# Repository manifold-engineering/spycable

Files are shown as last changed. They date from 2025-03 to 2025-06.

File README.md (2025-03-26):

# Manifold Spycable  
**_Work in Progress_**

**Manifold Spycable** is a project that aims to explore the boundaries of miniaturized embedded electronics by integrating a fully functional computer within a standard XLR connector. 

---

## Overview  
The Manifold Spycable comprises several components:

### 1. **The Spycable Device**  
- A single PCB computer designed to fit inside a standard XLR connector (such as the Neutrik NC3MMX or similar) - similar form factor as [Manifold PAT-MAT](https://github.com/manifold-engineering/pat-mat)
- Powered directly from standard 48V phantom power, commonly used in professional audio equipment.  
- Equipped with:  
  - **TI PCM1820/1821/1822 ADC** for audio data conversion.  
  - **ESP8685 MCU** based on the RISC-V ESP32-C3 core with Wi-Fi capability.  
- Features a **u.FL IPEX connector** for a Wi-Fi antenna. A detailed evaluation of compatible antennas (e.g., Fractus Compact Reach Xtend with coax cable) will be added later.  
- Designed to allow space for a microphone cable to pass through, enabling the creation of standard-looking XLR cables capable of audio data transmission and recording.

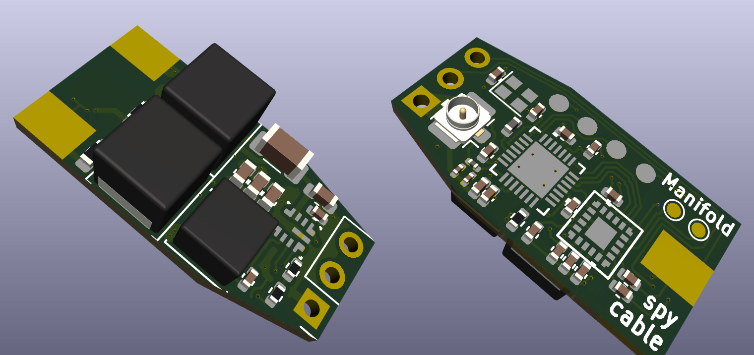
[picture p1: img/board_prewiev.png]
Board preview


### 2. **Firmware**  
Custom firmware for the ESP8685 to handle audio data acquisition from the ADC and real-time data transmission over Wi-Fi.

### 3. **Receiver Software**  
Software for standaerd computer systems to process the incoming audio data streams. Possible functions might include audio file recording and real-time playback.

---
### Development Stage  
This project is in its **early development stage**. Currently, only the hardware design for the device is ready. Firmware and receiver software development are still in progress.

**Note**: This project may have potential data security implications if used in unintended ways. However, it is intended purely for educational, experimental, and demonstration purposes.  

---

## Licensing  
This project is licensed under the **MIT License**. See the `LICENSE` file for more information.

---

## Future Development  
Stay tuned for:  
- Firmware updates for the embedded ESP8685.  
- Antenna recommendations and performance benchmarks.  
- Receiver software to enable audio recording and playback.

---

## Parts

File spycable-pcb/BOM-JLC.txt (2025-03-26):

BUCK DC DC PMIC	https://jlcpcb.com/partdetail/1973381-LMR36506MSCQRPERQ1/C1882561
C MLCC input LC	https://jlcpcb.com/partdetail/14236-CL31A106KBHNNNE/C13585
L input LC 	https://jlcpcb.com/partdetail/179374-FNR5040S502MT/C167991
C DC DC Out	https://jlcpcb.com/partdetail/71320-0603X106K160NT/C70225
L DC DC buck	https://jlcpcb.com/partdetail/179275-FNR4030S680MT/C167892 or https://jlcpcb.com/partdetail/179271-FNR4030S470MT/C167888
XTAL ESP	https://jlcpcb.com/partdetail/SeikoEpson-Q22FA12800332/C255899
ESP MCU		https://jlcpcb.com/partdetail/EspressifSystems-ESP8685H4/C4944062
Audio ADC	https://jlcpcb.com/partdetail/TexasInstruments-PCM1822IRTER/C5214995 or https://jlcpcb.com/partdetail/TexasInstruments-PCM1820IRTER/C5215004

aux: USB pogo https://www.aliexpress.com/item/1005006470782095.html

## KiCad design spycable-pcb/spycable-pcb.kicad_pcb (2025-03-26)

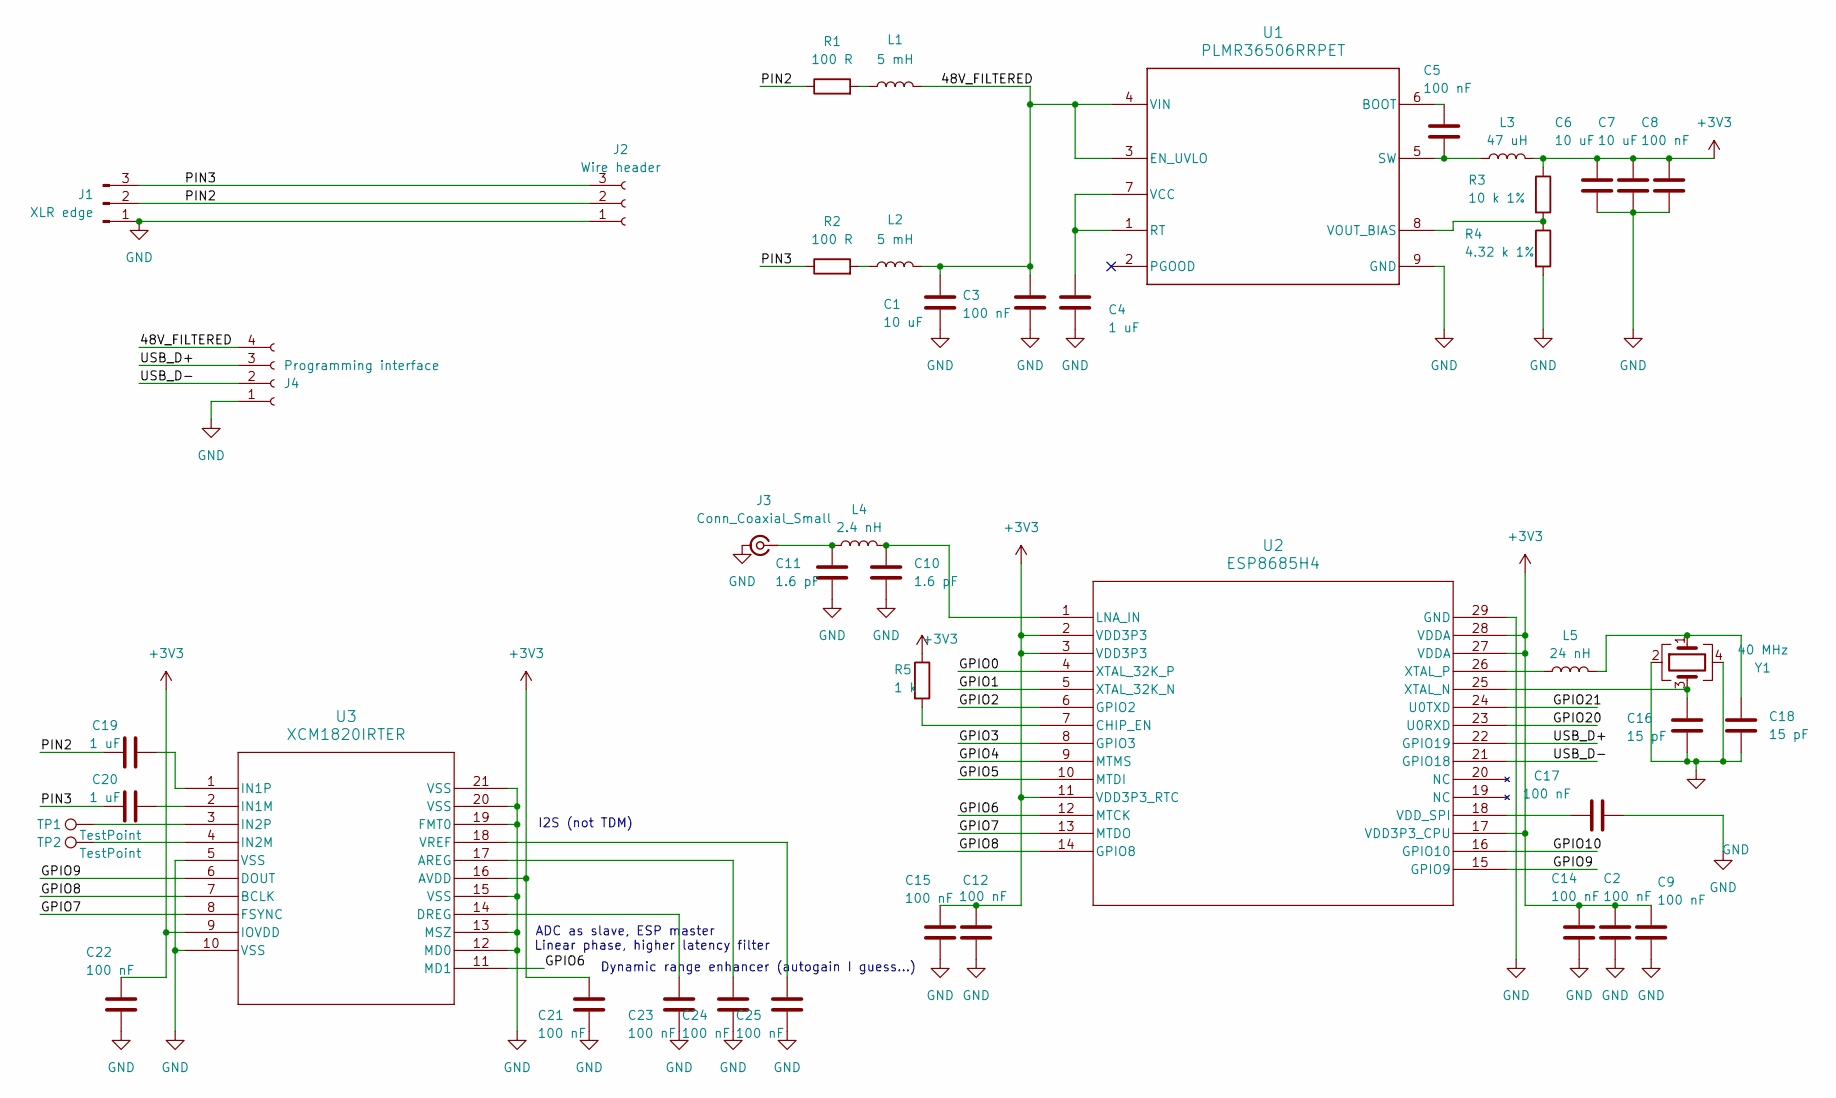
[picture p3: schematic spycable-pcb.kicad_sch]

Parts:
C1: 10 uF; C_1206_3216Metric
C2, C5, C9, C12, C14, C15, C17, C21, C22, C23, C24, C25: 100 nF; C_0402_1005Metric
C3, C8: 100 nF; C_0603_1608Metric
C4, C19, C20: 1 uF; C_0402_1005Metric
C6, C7: 10 uF; C_0603_1608Metric
C10, C11: 1.6 pF; C_0201_0603Metric
C16, C18: 15 pF; C_0402_1005Metric
J1: XLR edge; XLR_PCB
J2: Wire header; PinHeader_1x03_P2.54mm_Vertical
J3: Conn_Coaxial_Small; U.FL_Hirose_U.FL-R-SMT-1_Vertical
J4: Programming interface; USB pogo pads
L1, L2: 5 mH; L_Changjiang_FNR5040S
L3: 47 uH; L_Changjiang_FNR4030S
L4: 2.4 nH; L_0201_0603Metric
L5: 24 nH; L_0402_1005Metric
R1, R2: 100 R; R_0603_1608Metric
R3: 10 k 1%; R_0402_1005Metric
R4: 4.32 k 1%; R_0402_1005Metric
R5: 1 k; R_0402_1005Metric
TP1, TP2: TestPoint; TestPoint_Pad_D1.0mm
U1: PLMR36506RRPET; RPE0009A-MFG
U2: ESP8685H4; QFN284X4_EXP
U3: XCM1820IRTER; QFN_820IRTER_TEX
Y1: 40 MHz; Crystal_SMD_2016-4Pin_2.0x1.6mm

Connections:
+3V3: C2.1, C6.1, C7.1, C8.1, C9.1, C12.2, C14.1, C15.2, C21.2, C22.2, L3.2, R3.1, R5.1, U2.2 (VDD3P3), U2.3 (VDD3P3), U2.11 (VDD3P3_RTC), U2.17 (VDD3P3_CPU), U2.27 (VDDA), U2.28 (VDDA), U3.9 (IOVDD), U3.16 (AVDD)
/48V_FILTERED: C1.2, C3.1, J4.4, L1.2, L2.2, U1.3 (EN_UVLO), U1.4 (VIN)
/GPIO0: U2.4 (XTAL_32K_P)
/GPIO1: U2.5 (XTAL_32K_N)
/GPIO2: U2.6 (GPIO2)
/GPIO3: U2.8 (GPIO3)
/GPIO4: U2.9 (MTMS)
/GPIO5: U2.10 (MTDI)
/GPIO6: U2.12 (MTCK), U3.11 (MD1)
/GPIO7: U2.13 (MTDO), U3.8 (FSYNC)
/GPIO8: U2.14 (GPIO8), U3.7 (BCLK)
/GPIO9: U2.15 (GPIO9), U3.6 (DOUT)
/GPIO10: U2.16 (GPIO10)
/GPIO20: U2.23 (U0RXD)
/GPIO21: U2.24 (U0TXD)
/PIN2: C19.1, J1.2, J2.2, R1.1
/PIN3: C20.1, J1.3, J2.3, R2.1
/USB_D+: J4.3, U2.22 (GPIO19)
/USB_D-: J4.2, U2.21 (GPIO18)
GND: C1.1, C2.2, C3.2, C4.2, C6.2, C7.2, C8.2, C9.2, C10.1, C11.2, C12.1, C14.2, C15.1, C16.2, C17.2, C18.2, C21.1, C22.1, C23.1, C24.1, C25.1, J1.1, J2.1, J3.2 (Ext), J4.1, R4.2, U1.9 (GND), U2.29 (GND), U3.5 (VSS), U3.10 (VSS), U3.12 (MD0), U3.13 (MSZ), U3.15 (VSS), U3.19 (FMT0), U3.20 (VSS), U3.21 (VSS), Y1.2, Y1.4
unnamed: C18.1, L5.2, Y1.1
unnamed: C11.1, J3.1 (In), L4.1
unnamed: L1.1, R1.2
unnamed: L2.1, R2.2
unnamed: C5.1, U1.6 (BOOT)
unnamed: C4.1, U1.1 (RT), U1.7 (VCC)
unnamed: C5.2, L3.1, U1.5 (SW)
unnamed: R3.2, R4.1, U1.8 (VOUT_BIAS)
unnamed: R5.2, U2.7 (CHIP_EN)
unnamed: C10.2, L4.2, U2.1 (LNA_IN)
unnamed: C17.1, U2.18 (VDD_SPI)
unnamed: C16.1, U2.25 (XTAL_N), Y1.3
unnamed: L5.1, U2.26 (XTAL_P)
unnamed: C24.2, U3.17 (AREG)
unnamed: C23.2, U3.14 (DREG)
unnamed: C20.2, U3.2 (IN1M)
unnamed: C19.2, U3.1 (IN1P)
unnamed: TP2.1, U3.4 (IN2M)
unnamed: TP1.1, U3.3 (IN2P)
unnamed: C25.2, U3.18 (VREF)

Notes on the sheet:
I2S (not TDM)
ADC as slave, ESP master
Dynamic range enhancer (autogain I guess...)
Linear phase, higher latency filter

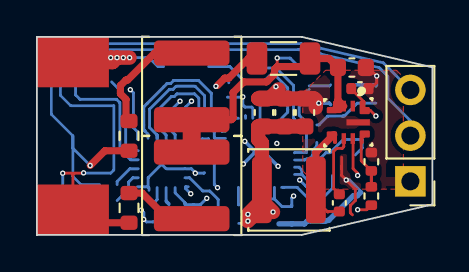
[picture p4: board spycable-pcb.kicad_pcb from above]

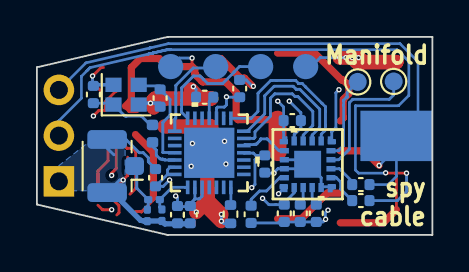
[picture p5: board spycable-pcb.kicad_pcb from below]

Board: 4 copper layers, 22.0 x 11.0 mm, 44 parts (27 on the bottom side), 31 nets.

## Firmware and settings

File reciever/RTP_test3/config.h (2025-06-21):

#ifndef CONFIG_H
#define CONFIG_H


#define SOCKET_BUFFER_SIZE 40960


#define DEFAULT_UDP_PORT 5004
#define DEFAULT_STREAM_CAPACITY 8
#define DEFAULT_SAMPLES_CAPACITY 480000


#define SAMPLE_RATE 48000

#endif // CONFIG_H

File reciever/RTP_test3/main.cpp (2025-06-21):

#include <iostream>

#include "audioringbuffer.h"
#include "rtpserver.h"


#define TEST_BUFF_SIZE_A 10
#define TEST_BUFF_SIZE_B 512
#define TEST_CHUNK_SIZE 240

#define TEST_SAMPLERATE 48000
#define TEST_CLOCK_FREQUENCY 8000
#define CLOCK_TICKS_PER_CHUNK TEST_CHUNK_SIZE * TEST_CLOCK_FREQUENCY / TEST_SAMPLERATE

int main(int argc, char *argv[])
{
    RTPServer server;

    server.init();
    server.run();
}

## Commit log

2025-03-26 Initial commit, first hardware revision seems done
    [spycable-pcb.kicad_pcb, spycable-pcb.kicad_sch]
2025-05-14 Including portaudio sources
    [README.configure.txt]
2025-05-19 Data insertion WiP, now metadata in sparse tree struct, audio sample not ready yet
2025-05-28 buffer ingestion seems preliminary tested and fixed
    [main.cpp]
